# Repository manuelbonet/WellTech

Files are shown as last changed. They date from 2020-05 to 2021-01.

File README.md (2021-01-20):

# WellTech

WellTech is a school project developed by Manuel Bonet, Martín Subirá and Pablo Mellado in order to use technology as a way to improve our daily lives as students and change the ways we learn. To achieve this goal, we decided to create two different devices: a [weather station](WeatherStation) and a [classroom quality sensor](ClassroomQualitySensor).

The classroom quality sensors measure parameters that we consider key to be able to study in a comfortable environment such as temperature, humidity, sound volume and the CO<sub>2</sub> concentration in air. This last value might seem weird, but there are several studies which have found a relationship between the level of carbon dioxide in the air and the cognitive ability of a person. Given that this is precisely an ability that students need to put in practice, it is a very important parameter to control.

We have also created a weather station that monitors data such as temperature, pressure, humidiity, wind speed and direction and CO<sub>2</sub> concentration. This is because we consider that a very effective way to have students learn information is through practical activities which can be connected to as many subjects as possible. We believe that such a project could be used in a variety of subjects such as Technology (creation of the structure and the circuit), Computer Science (coding), Physics and Chemistry (understanding of meteorological phenomena) and Mathematics (statistics, processing of the raw data). Another advantage to such a project is that pupils have an active role in learning which makes it more difficult to distract themselves, and being able to collect their own data provides an incentive not present in traditional theoretical exercises.

The data collected by these two devices is sent through the [TheThingsNetwork](https://www.thethingsnetwork.org/) LoRaWAN network and the information is stored using [ThingSpeak](https://thingspeak.com/). As a way to debug any possible problem there might be, they also send the data they collect through the serial port and through Bluetooth with the pairing code 2468.

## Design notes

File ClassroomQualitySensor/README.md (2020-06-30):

# Classroom quality sensor

## Parameters

The parameters that the classroom quality sensor measures are:
* Temperature (°C)
* Pressure (hPa)
* Relative humidity (%)
* Volume (dB)
* CO<sub>2</sub> concentration in air (ppm)

## Hardware

In terms of processing power, we decided to go for a TTGO LoRa32 with an OLED screen, which provides LoRaWAN, Bluetooth and WiFi (not used) communication as well as a handy screen from which to easily debug any possible problem.

To power the sensor, it is as simple as using a 5V 1A micro USB phone charger.

The sensors used for the project are:
* BME280 (with I<sup>2</sup>C output)
* Three electret microphones
  * One without any gain (i.e. the capsule itself)
  * One with adjustable gain set at minimum
  * One with adjustable gain set at maximum
* MH-Z14A
* Push button (to calibrate the CO<sub>2</sub>sensor if it were needed)

A functional diagram of the wiring can be found below.

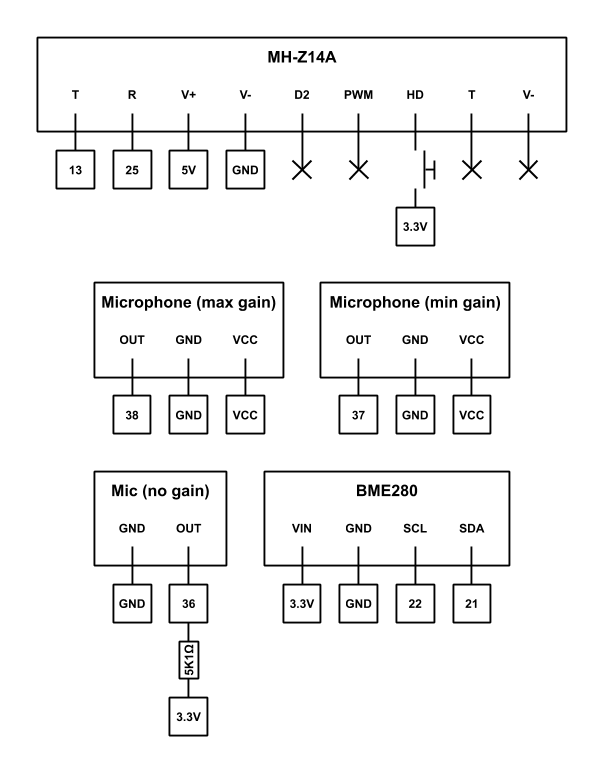
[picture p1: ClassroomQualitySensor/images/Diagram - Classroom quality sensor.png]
Wiring


## Software

The TTGO LoRa32 board can be programmed with Arduino IDE after installing the board through the board manager. The main code (classroomquality.ino) depends on the libraries that have to be added before trying to compile it. The libraries are property of their respective owners and they are under their respective licenses. I have uploaded them to the folder as a way to simplify finding and installing them.

The measured values are sent through the TTN network as comma-separated values and they have to be parsed before they arrive to the ThingSpeak integration. To decode and convert this data, the following snippets are needed under "Payload format":

```javascript
function Decoder(bytes, port) {
  while (bytes[bytes.length - 1] === 0){
    bytes.pop();
  }
  
  text = "";
  
   for (i = 0; i < bytes.length; i++){
     text += String.fromCharCode(bytes[i]);
   }
   
   return {"text": text};
}
```

```javascript
function Converter(decoded, port) {
  
   dividedText = decoded["text"].split("/");
   
   temperature = parseFloat(dividedText[0]);
   pressure = parseFloat(dividedText[1]);
   humidity = parseFloat(dividedText[2]);
   volume = parseFloat(dividedText[3]);
   CO2 = parseFloat(dividedText[4]);
   
   convertedData = {};
   
   if(!isNaN(temperature)){
     convertedData["field1"] = temperature;
   }
   
   if(!isNaN(pressure)){
     convertedData["field2"] = pressure;
   } 
   
   if(!isNaN(humidity)){
     convertedData["field3"] = humidity;
   }
   
   if(!isNaN(volume)){
     convertedData["field4"] = volume;
   }
   
   if(!isNaN(CO2)){
     convertedData["field5"] = CO2;
   }
  
  return convertedData;
}
```

These two snippets are prepared to have the ThingSpeak channels in the same order as written in the [Parameters](#parameters) section.

## Sound calibration

Due to the fact that electret microphones do not output the volume of the sound they capture in decibels, a relationship between the peak-to-peak voltage and the volume needs to be found. [Here](https://docs.google.com/spreadsheets/d/1mHTgkDXV53TCKcUPq5pmppE6GQpHShiHMCgk4wV-P8s/edit?usp=sharing) is a spreadsheet that calculates this equivalence given some empirical measurements.

## Box

The sensors have to fit in a box, which should have enough holes so that both air and sound can easily get inside. We have provided a box which directly fits a 15x9 cm perfboard and holes big enough to achieve this.

## Cost

This is a cheaper project, its cost is of around €45. The two main costs of the classroom quality sensor are the TTGO LoRa32 and the MH-Z14A, each costing around €17.

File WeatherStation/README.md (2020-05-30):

# Weather station

## Parameters

The parameters that the weather station provides are:
* Temperature (°C)
* Apparent temperature (°C)
* Pressure (hPa)
* Relative humidity (%)
* Dew point (°C)
* Wind speed (km/h)
* Wind direction (in increments of 22.5°)
* CO<sub>2</sub> concentration in air (ppm)

## Hardware

In terms of processing power, we decided to go for a TTGO LoRa32 with an OLED screen, which provides LoRaWAN, Bluetooth and WiFi (not used) communication as well as a handy screen from which to easily debug any possible problem.

Regarding powering the weather station, we went for a 12V solar panel. This is because we wanted to be able to place it in the most optimal location to take good readings without having to be close to a power outlet. Dtue to this, we also had to create a sturdy structure in order to place the solar panel on top. The reason why we chose a 12V system specifically is because the anemometer and the wind vane run at that voltage, but because the CO<sub>2</sub> sensor and the TTGo LoRa32 need to be powered with 5V we also had to include a 12V-5V buck converter. All other components run at 3.3V, but the TTGO LoRa32 board generates this voltage.

The sensors used for the project are:
* DS18B20
* BME280 (with I<sup>2</sup>C output)
* Anemometer and wind vane (we used [these](https://es.aliexpress.com/item/33019729997.html), specifically the ones that output a 0-5V signal)
* Trimmer potentiometer (to calibrate the wind direction)
* MH-Z14A
* Push button (to calibrate the CO<sub>2</sub> sensor if it were needed)

A functional diagram of the wiring can be found below.

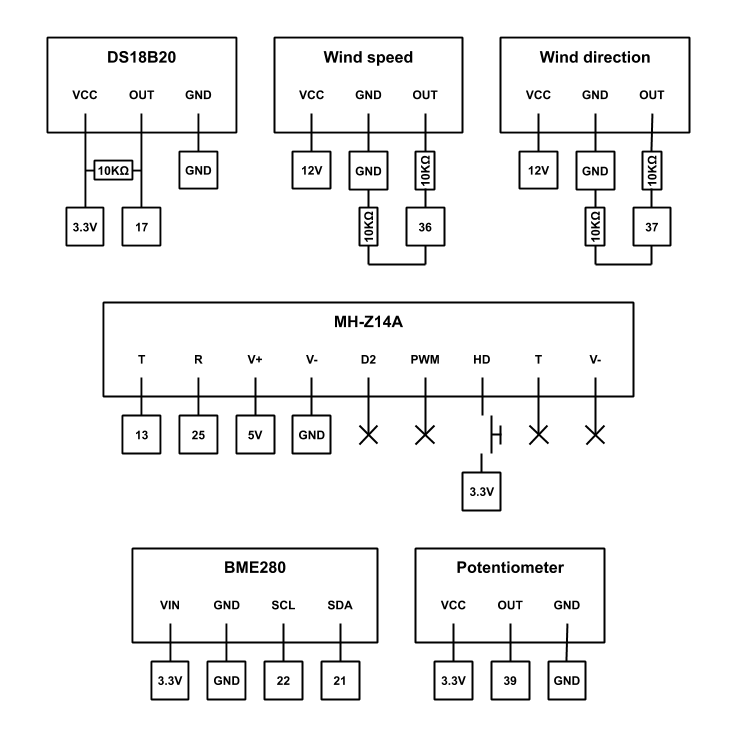
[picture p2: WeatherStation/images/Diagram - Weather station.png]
Wiring


## Software

The TTGO LoRa32 board can be programmed with Arduino IDE after installing the board through the board manager. The main code (weatherstation.ino) depends on the libraries that have to be added before trying to compile it. The libraries are property of their respective owners and they are under their respective licenses. I have uploaded them to the folder as a way to simplify finding and installing them.

The measured values are sent through the TTN network as comma-separated values and they have to be parsed before they arrive to the ThingSpeak integration. To decode and convert this data, the following snippets are needed under "Payload format":

```javascript
function Decoder(bytes, port) {
  while (bytes[bytes.length - 1] === 0){
    bytes.pop();
  }
  
  text = "";
  
   for (i = 0; i < bytes.length; i++){
     text += String.fromCharCode(bytes[i]);
   }
   
   return {"text": text};
}
```

```javascript
function Converter(decoded, port) {
  
   dividedText = decoded["text"].split("/");
   
   temperature = parseFloat(dividedText[0]);
   apparentTemperature = parseFloat(dividedText[1]);
   pressure = parseFloat(dividedText[2]);
   humidity = parseFloat(dividedText[3]);
   dewPoint = parseFloat(dividedText[4]);
   windSpeed = parseFloat(dividedText[5]);
   windDirection = parseFloat(dividedText[6]);
   CO2 = parseFloat(dividedText[7]);
   
   convertedData = {};
   
   if(!isNaN(temperature)){
     convertedData["field1"] = temperature;
   }
   
   if(!isNaN(apparentTemperature)){
     convertedData["field2"] = apparentTemperature;
   }
   
   if(!isNaN(pressure)){
     convertedData["field3"] = pressure;
   }

   if(!isNaN(humidity)){
     convertedData["field4"] = humidity;
   }

   if(!isNaN(dewPoint)){
     convertedData["field5"] = dewPoint;
   }
   
   if(!isNaN(windSpeed)){
     convertedData["field6"] = windSpeed;
   }
   
   if(!isNaN(windDirection)){
     convertedData["field7"] = windDirection;
   }

   if(!isNaN(CO2)){
     convertedData["field8"] = CO2;
   }
  
  return convertedData;
}
```

These two snippets are prepared to have the ThingSpeak channels in the same order as written in the [Parameters](#parameters) section.

## Best practices for measurements

There are several things that should be considered when deciding the structure and the location for the weather station collected in the World Meteorological Organizations' [Guide to Meteorological Instruments and Methods of Observation](https://library.wmo.int/index.php?lvl=notice_display&id=12407). However, some of these requirements turn out to be very difficult to satisfy with a setup like ours, especially those related to wind. Nevertheless, the data collected with such a weather station, although not perfect, is more than good enough to be able to learn from.

Given that these criteria are almost impossible to follow in the context of a school, it is very important to place the anemometer and vane as high and as far away as possible from any obstacle even if they are not met. Therefore, we suggest placing the weather station as far away from any tall buildings as possible and having the anemometer and wind vane at a height of at least 2 m.

## Solar power

If the weather station is solar powered, other factors should also be considered, the main one being that the weather station should be placed in such a place where ideally no shadow can be cast over the solar panel.

In terms of which solar panel and battery to choose, it is important to calculate their sizes. There are websites online and mobile apps that make this process easier. The power consumption of the weather station (with a 30% safety margin) is of 1.8W or 43.2Wh/day. Regarding the position of the solar panel, it should be pointing towards the South in the Northern Hemisphere and the North in the Southern Hemisphere, and its tilt should be appropriate to the season of year and the geographical latitude.

## Cost

This is not a cheap project, it cost us around €300 in components to build it. However, there are things that can be removed to lower the price to a much more affordable price point.

Powering the weather station through solar power is one of the main extra costs. Around €100 of that price comes directly from the solar panel, the charge controller and the battery we used. Removing the solar panel would also mean that the cost of the structure (€100) could decrease as it would not have to hold these components.

The other main source of price comes from the anemometer and the wind vane, which cost around €65. If the wind vane were not to be used, the trimmer potentiometer would no longer be necessary. However, in order to do this properly, the main code and the TTN snippets would have to be changed.

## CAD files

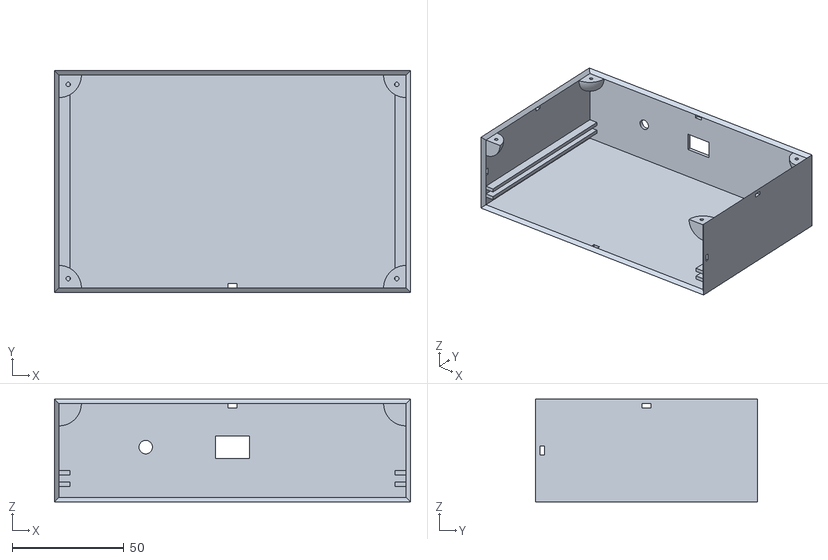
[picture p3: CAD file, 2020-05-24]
ClassroomQualitySensor/box/Box - Classroom quality sensor.stl
159.0 x 99.0 x 46.0

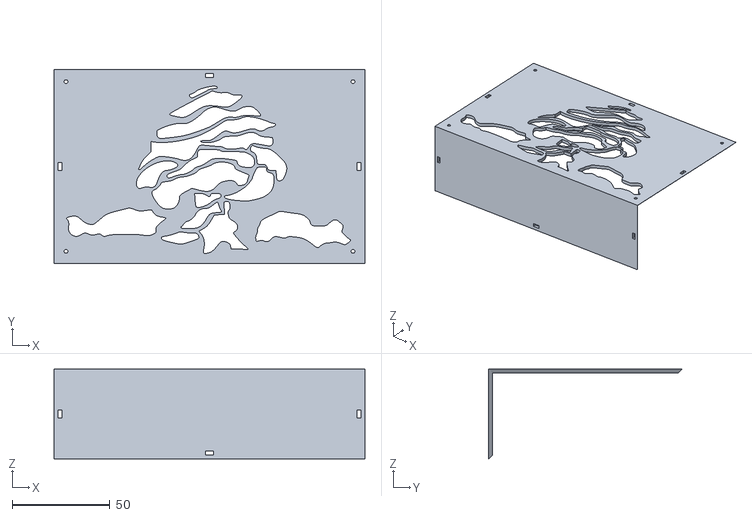
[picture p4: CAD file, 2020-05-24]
ClassroomQualitySensor/box/Lid - Classroom quality sensor.stl
159.0 x 99.0 x 46.0

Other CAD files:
ClassroomQualitySensor/box/Classroom quality sensor.f3d
ClassroomQualitySensor/box/Classroom quality sensor.skp

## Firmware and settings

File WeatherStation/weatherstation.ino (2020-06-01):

//VERSION
//Date: 2020-05-31

//PINS
//Screen: 4 (SDA), 15 (SCL), 16 (RST)
//General I2C (BME280): 21 (SDA), 22 (SCL)
//OneWire: 17
//Wind speed: 36
//Wind direction: 37
//Correction angle potentiometer: 39
//Serial (CO2): 13 (RX), 25 (TX)

//BEFORE LOADING THE CODE
//Remember to change NWKSKEY, APPSKEY and DEVADDR to whichever values are set on your TheThingsNetwork application and device
//If you are in range of a multiple channel gateway, change MULTICHANNEL to 1
//Before using the values of decibels, remember to calibrate the microphones

#include <math.h>
#include <lmic.h>
#include <hal/hal.h>
#include <SPI.h>
#include <Wire.h>
#include <Adafruit_SSD1306.h>
#include <Adafruit_BME280.h>
#include <DallasTemperature.h>
#include <BluetoothSerial.h>

static const PROGMEM u1_t NWKSKEY[16] = { 0x00, 0x00, 0x00, 0x00, 0x00, 0x00, 0x00, 0x00, 0x00, 0x00, 0x00, 0x00, 0x00, 0x00, 0x00, 0x00 };
static const PROGMEM u1_t APPSKEY[16] = { 0x00, 0x00, 0x00, 0x00, 0x00, 0x00, 0x00, 0x00, 0x00, 0x00, 0x00, 0x00, 0x00, 0x00, 0x00, 0x00 };

static const u4_t DEVADDR = 0x00000000 ;

#define MULTICHANNEL 0

void os_getArtEui (u1_t* buf) { }
void os_getDevEui (u1_t* buf) { }
void os_getDevKey (u1_t* buf) { }

#define WIND_INTERVAL 1
#define TX_INTERVAL 60

unsigned long lastWind = - WIND_INTERVAL * 1000;
unsigned long lastTX = - TX_INTERVAL * 1000;
unsigned long millisOverflows = -1;
bool sendValues = false;

const byte disableABC[] = {0xFF, 0x01, 0x79, 0xA0, 0x00, 0x00, 0x00, 0x00, 0xE6};
const byte readCO2[] = {0xFF, 0x01, 0x86, 0x00, 0x00, 0x00, 0x00, 0x00, 0x79};

float insideTemperature;
float temperature;
float apparentTemperature;
float dewPoint;
float pressure;
float insideHumidity;
float humidity;
float windSpeed;
float maxWindSpeed;
float windDirection;
float adjustedWindDirection;
float cumulativeWindX;
float cumulativeWindY;
float averageWindDirection;
float correctionAngle;
float CO2;

String text;
static uint8_t textBytes[256];

const lmic_pinmap lmic_pins = {
  .nss = 18,
  .rxtx = LMIC_UNUSED_PIN,
  .rst = 14,
  .dio = {26, 33, 32},
};

Adafruit_SSD1306 display(128, 64, &Wire, 16);
Adafruit_BME280 bme280;
OneWire oneWire(17);
DallasTemperature ds18b20(&oneWire);
BluetoothSerial bluetooth;

void onEvent (ev_t ev) {
  Serial.print(os_getTime());
  Serial.print(": ");
  switch (ev) {
    case EV_SCAN_TIMEOUT:
      Serial.println(F("EV_SCAN_TIMEOUT"));
      break;
    case EV_BEACON_FOUND:
      Serial.println(F("EV_BEACON_FOUND"));
      break;
    case EV_BEACON_MISSED:
      Serial.println(F("EV_BEACON_MISSED"));
      break;
    case EV_BEACON_TRACKED:
      Serial.println(F("EV_BEACON_TRACKED"));
      break;
    case EV_JOINING:
      Serial.println(F("EV_JOINING"));
      break;
    case EV_JOINED:
      Serial.println(F("EV_JOINED"));
      break;
    case EV_RFU1:
      Serial.println(F("EV_RFU1"));
      break;
    case EV_JOIN_FAILED:
      Serial.println(F("EV_JOIN_FAILED"));
      break;
    case EV_REJOIN_FAILED:
      Serial.println(F("EV_REJOIN_FAILED"));
      break;
    case EV_TXCOMPLETE:
      Serial.println(F("EV_TXCOMPLETE (includes waiting for RX windows)"));
      if (LMIC.txrxFlags & TXRX_ACK)
        Serial.println(F("Received ack"));
      if (LMIC.dataLen) {
        Serial.println(F("Received "));
        Serial.println(LMIC.dataLen);
        Serial.println(F(" bytes of payload"));
      }
      break;
    case EV_LOST_TSYNC:
      Serial.println(F("EV_LOST_TSYNC"));
      break;
    case EV_RESET:
      Serial.println(F("EV_RESET"));
      break;
    case EV_RXCOMPLETE:
      Serial.println(F("EV_RXCOMPLETE"));
      break;
    case EV_LINK_DEAD:
      Serial.println(F("EV_LINK_DEAD"));
      break;
    case EV_LINK_ALIVE:
      Serial.println(F("EV_LINK_ALIVE"));
      break;
    default:
      Serial.println(F("Unknown event"));
      break;
  }

  Serial.println();
}

float analogReadVolts(unsigned int pin, unsigned int readings = 100) {
  float values[] = {0,    1,   77,  197,  318,  438,  564,  694,  811,  931, 1069, 1180, 1306, 1435, 1562, 1680, 1806, 1924, 2053, 2174, 2294, 2418, 2535, 2674, 2801, 2927, 3071, 3221, 3389, 3587, 3798, 4031, 4095, 4095};
  float volts[] =  {0,  0.1,  0.2,  0.3,  0.4,  0.5,  0.6,  0.7,  0.8,  0.9,  1.0,  1.1,  1.2,  1.3,  1.4,  1.5,  1.6,  1.7,  1.8,  1.9,  2.0,  2.1,  2.2,  2.3,  2.4,  2.5,  2.6,  2.7,  2.8,  2.9,  3.0,  3.1,  3.2,  3.3};

  long x = 0;

  for (int i = 0; i < readings; i++) {
    x += analogRead(pin);
    delayMicroseconds(500);
  }

  x /= readings;

  for (int i = 0; i < sizeof(values) / sizeof(values[0]); i++) {
    if (x <= values[i]) {

      if (i == 0) {
        return volts[0];
      }

      if (values[i - 1] == values[i]) {
        return (volts[i - 1] + volts[i]) / 2;
      }

      return (x - values[i - 1]) / (values[i] - values[i - 1]) * (volts[i] - volts[i - 1]) + volts[i - 1];
    }
  }
  return volts[sizeof(volts) / sizeof(volts[0]) - 1];
}

void setup() {
  Wire.begin(4, 15);
  Serial.begin(115200);
  Serial.println("Starting...");

  bluetooth.begin("Weather station");
  bluetooth.setPin("2468");

  Serial1.begin(9600, SERIAL_8N1, 13, 25);
  Serial1.write(disableABC, 9);

  display.begin(SSD1306_SWITCHCAPVCC, 0x3C);
  display.clearDisplay();
  display.setTextColor(SSD1306_WHITE);
  display.setCursor(0, 0);
  display.println("Starting...");
  display.display();

  Wire.begin(21, 22);
  bme280.begin();
  ds18b20.begin();

#ifdef VCC_ENABLE
  pinMode(VCC_ENABLE, OUTPUT);
  digitalWrite(VCC_ENABLE, HIGH);
  delay(1000);
#endif

  os_init();
  LMIC_reset();

#ifdef PROGMEM
  uint8_t appskey[sizeof(APPSKEY)];
  uint8_t nwkskey[sizeof(NWKSKEY)];
  memcpy_P(appskey, APPSKEY, sizeof(APPSKEY));
  memcpy_P(nwkskey, NWKSKEY, sizeof(NWKSKEY));
  LMIC_setSession (0x1, DEVADDR, nwkskey, appskey);
#else
  LMIC_setSession (0x1, DEVADDR, NWKSKEY, APPSKEY);
#endif

#if defined(CFG_eu868)
#if (MULTICHANNEL)
  LMIC_setupChannel(0, 868100000, DR_RANGE_MAP(DR_SF12, DR_SF7),  BAND_CENTI);
  LMIC_setupChannel(1, 868300000, DR_RANGE_MAP(DR_SF12, DR_SF7B), BAND_CENTI);
  LMIC_setupChannel(2, 868500000, DR_RANGE_MAP(DR_SF12, DR_SF7),  BAND_CENTI);
  LMIC_setupChannel(3, 867100000, DR_RANGE_MAP(DR_SF12, DR_SF7),  BAND_CENTI);
  LMIC_setupChannel(4, 867300000, DR_RANGE_MAP(DR_SF12, DR_SF7),  BAND_CENTI);
  LMIC_setupChannel(5, 867500000, DR_RANGE_MAP(DR_SF12, DR_SF7),  BAND_CENTI);
  LMIC_setupChannel(6, 867700000, DR_RANGE_MAP(DR_SF12, DR_SF7),  BAND_CENTI);
  LMIC_setupChannel(7, 867900000, DR_RANGE_MAP(DR_SF12, DR_SF7),  BAND_CENTI);
  LMIC_setupChannel(8, 868800000, DR_RANGE_MAP(DR_FSK,  DR_FSK),  BAND_MILLI);
#else
  LMIC_setupChannel(0, 868100000, DR_RANGE_MAP(DR_SF12, DR_SF7),  BAND_CENTI);
  LMIC_setupChannel(1, 868100000, DR_RANGE_MAP(DR_SF12, DR_SF7),  BAND_CENTI);
  LMIC_setupChannel(2, 868100000, DR_RANGE_MAP(DR_SF12, DR_SF7),  BAND_CENTI);
  LMIC_setupChannel(3, 868100000, DR_RANGE_MAP(DR_SF12, DR_SF7),  BAND_CENTI);
  LMIC_setupChannel(4, 868100000, DR_RANGE_MAP(DR_SF12, DR_SF7),  BAND_CENTI);
  LMIC_setupChannel(5, 868100000, DR_RANGE_MAP(DR_SF12, DR_SF7),  BAND_CENTI);
  LMIC_setupChannel(6, 868100000, DR_RANGE_MAP(DR_SF12, DR_SF7),  BAND_CENTI);
  LMIC_setupChannel(7, 868100000, DR_RANGE_MAP(DR_SF12, DR_SF7),  BAND_CENTI);
  LMIC_setupChannel(8, 868100000, DR_RANGE_MAP(DR_SF12, DR_SF7),  BAND_CENTI);
#endif
#elif defined(CFG_us915)
  LMIC_selectSubBand(1);
#endif

  LMIC_setLinkCheckMode(0);
  LMIC.dn2Dr = DR_SF9;
  LMIC_setDrTxpow(DR_SF7, 14);
}

void loop() {
  unsigned long millisNow = millis();

  if ((millisNow >= (unsigned long)(lastWind + 1000 * WIND_INTERVAL)) && (((unsigned long)(lastWind + 1000 * WIND_INTERVAL) > lastWind) || ((unsigned long)(millisNow + 1000 * WIND_INTERVAL) > millisNow))) {
    lastWind = millisNow;

    windSpeed = 43.2 * analogReadVolts(36);
    if (windSpeed > maxWindSpeed) {
      maxWindSpeed = windSpeed;
    }
    windDirection = round(6.95652173913 * analogReadVolts(37)) * 22.5;
    correctionAngle = floor(analogReadVolts(39) * 5) * 22.5; if (correctionAngle == 360) correctionAngle = 337.5;
    adjustedWindDirection = windDirection - correctionAngle; while (adjustedWindDirection >= 360) adjustedWindDirection -= 360;  while (adjustedWindDirection < 0) adjustedWindDirection += 360;
    cumulativeWindX += cos(adjustedWindDirection * PI / 180.0);
    cumulativeWindY += sin(adjustedWindDirection * PI / 180.0);

    Wire.begin(4, 15);

    display.fillRect(0, 32, 128, 16, 0);
    display.setCursor(0, 32);
    display.println(String(windSpeed, 2) + "km/h " + String(adjustedWindDirection) + "*");
    display.println("WCA: " + String(correctionAngle, 1) + "*");
    display.display();
  }

  if ((millisNow >= (unsigned long)(lastTX + 1000 * TX_INTERVAL)) && (((unsigned long)(lastTX + 1000 * TX_INTERVAL) > lastTX) || ((unsigned long)(millisNow + 1000 * TX_INTERVAL) > millisNow))) {
    if (millisNow < lastTX){
      millisOverflows++;
    }

    lastTX = millis();

    Wire.begin(21, 22);

    ds18b20.requestTemperatures();
    insideTemperature = bme280.readTemperature();
    temperature = ds18b20.getTempCByIndex(0);
    delay(50);
    pressure = bme280.readPressure() / 100;
    delay(50);
    insideHumidity = bme280.readHumidity();
    humidity = constrain(insideHumidity * exp((18.768 - insideTemperature / 234.5) * (insideTemperature / (257.1 + insideTemperature)) - (18.768 - temperature / 234.5) * (temperature / (257.1 + temperature))), 0, 100);
    dewPoint = 1.0 / 2.0 * (4379.991 - 234.5 * (log(humidity / 100) + (18.678 - temperature / 234.5) * (temperature / (257.14 + temperature))) - sqrt(pow(234.5 * (log(humidity / 100) + (18.678 - temperature / 234.5) * (temperature / (257.14 + temperature))) - 4379.991, 2) - 241197.32 * (log(humidity / 100) + (18.678 - temperature / 234.5) * (temperature / (257.14 + temperature)))));
    averageWindDirection = round(atan2(cumulativeWindY, cumulativeWindX) / PI * 180.0 / 22.5) * 22.5; while (averageWindDirection < 0) averageWindDirection += 360;
    if (temperature >= 26 && humidity >= 40) {
      apparentTemperature = -8.78469476 + 1.61139411 * temperature + 2.338548839 * humidity - 0.14611605 * temperature * humidity - 0.012308094 * pow(temperature, 2) - 0.016424828 * pow(humidity, 2) + 0.002211732 * pow(temperature, 2) * humidity + 0.00072546 * temperature * pow(humidity, 2) - 0.000003582 * pow(temperature, 2) * pow(humidity, 2);
    } else if (temperature <= 10 && maxWindSpeed >= 3.2) {
      apparentTemperature =  13.1267 + 0.6215 * temperature - 11.37 * pow(maxWindSpeed * 1.5, 0.16) + 0.3965 * temperature * pow(maxWindSpeed * 1.5, 0.16);
    } else {
      apparentTemperature = temperature;
    }

    byte bufferCO2[9];
    while (Serial1.available()) {
      Serial1.read();
    }
    Serial1.write(readCO2, 9);
    Serial1.readBytes(bufferCO2, 9);
    CO2 = (unsigned int)(bufferCO2[2] && B00011111) * 256 + (unsigned int)bufferCO2[3];

    uint64_t fullMillis = lastTX + 4294967296 * millisOverflows;
    unsigned long fullMillisA = fullMillis / 1E16;
    unsigned long fullMillisB = (fullMillis - fullMillisA * 1E16) / 1E8;
    unsigned long fullMillisC = fullMillis - fullMillisA - fullMillisB;

    uint64_t tempTX = fullMillis;
    int dayTX = 0;
    int hourTX = 0;
    int minuteTX = 0;

    while (tempTX >= 86400E3) {
      tempTX -= 86400E3;
      dayTX++;
    }
    while (tempTX >= 3600E3) {
      tempTX -= 3600E3;
      hourTX++;
    }
    while (tempTX >= 60E3) {
      tempTX -= 60E3;
      minuteTX++;
    }

    Serial.print("Time: day ");
    Serial.print(dayTX);
    Serial.print(" ");
    if (hourTX < 10) {
      Serial.print("0");
    }
    Serial.print(hourTX);
    Serial.print(":");
    if (minuteTX < 10) {
      Serial.print("0");
    }
    Serial.print(minuteTX);
    Serial.print(" (");
    if (fullMillisA!=0){
      Serial.print(fullMillisA);
    }
    if (fullMillisB!=0){
      Serial.print(fullMillisB);
    } else if (fullMillisA!=0){
      Serial.print("00000000");
    }
    Serial.print(fullMillisC);
    Serial.println(" ms)");

    Serial.print("Inside temperature: ");
    Serial.print(insideTemperature, 2);
    Serial.println(" °C");

    Serial.print("Outside temperature: ");
    Serial.print(temperature, 2);
    Serial.println(" °C");

    Serial.print("Dew point: ");
    Serial.print(dewPoint, 2);
    Serial.println(" °C");

    Serial.print("Atmospheric pressure: ");
    Serial.print(pressure, 2);
    Serial.println(" hPa");

    Serial.print("Inside humidity: ");
    Serial.print(insideHumidity, 2);
    Serial.println(" %");

    Serial.print("Outside humidity: ");
    Serial.print(humidity, 2);
    Serial.println(" %");

    Serial.print("Maximum wind speed: ");
    Serial.print(maxWindSpeed, 2);
    Serial.println(" km/h");

    Serial.print("Average wind direction: ");
    Serial.print(averageWindDirection, 1);
    Serial.println("°");

    Serial.print("Apparent temperature: ");
    Serial.print(apparentTemperature, 2);
    Serial.println(" °C");

    Serial.print("CO2: ");
    Serial.print(CO2, 0);
    Serial.println(" ppm");

    bluetooth.print("Time: day ");
    bluetooth.print(dayTX);
    bluetooth.print(" ");
    if (hourTX < 10) {
      bluetooth.print("0");
    }
    bluetooth.print(hourTX);
    bluetooth.print(":");
    if (minuteTX < 10) {
      bluetooth.print("0");
    }
    bluetooth.print(minuteTX);
    bluetooth.print(" (");
    if (fullMillisA!=0){
      bluetooth.print(fullMillisA);
    }
    if (fullMillisB!=0){
      bluetooth.print(fullMillisB);
    } else if (fullMillisA!=0){
      bluetooth.print("00000000");
    }
    bluetooth.print(fullMillisC);
    bluetooth.println(" ms)");

    bluetooth.print("Inside temperature: ");
    bluetooth.print(insideTemperature, 2);
    bluetooth.println(" *C");

    bluetooth.print("Outside temperature: ");
    bluetooth.print(temperature, 2);
    bluetooth.println(" *C");

    bluetooth.print("Dew point: ");
    bluetooth.print(dewPoint, 2);
    bluetooth.println(" *C");

    bluetooth.print("Atmospheric pressure: ");
    bluetooth.print(pressure, 2);
    bluetooth.println(" hPa");

    bluetooth.print("Inside humidity: ");
    bluetooth.print(insideHumidity, 2);
    bluetooth.println(" %");

    bluetooth.print("Outside humidity: ");
    bluetooth.print(humidity, 2);
    bluetooth.println(" %");

    bluetooth.print("Maximum wind speed: ");
    bluetooth.print(maxWindSpeed, 2);
    bluetooth.println(" km/h");

    bluetooth.print("Average wind direction: ");
    bluetooth.print(averageWindDirection, 1);
    bluetooth.println("*");

    bluetooth.print("Apparent temperature: ");
    bluetooth.print(apparentTemperature, 2);
    bluetooth.println(" *C");

    bluetooth.print("CO2: ");
    bluetooth.print(CO2, 0);
    bluetooth.println(" ppm");
    bluetooth.println();

    text = "";
    text += (-80 <= temperature && temperature <= 80) ? String(temperature, 2) : "";
    text += "/";
    text += (-80 <= apparentTemperature && apparentTemperature <= 80) ? String(apparentTemperature, 2) : "";
    text += "/";
    text += (0 <= pressure && pressure <= 2000) ? String(pressure, 2) : "";
    text += "/";
    text += (0 <= humidity && humidity <= 100) ? String(humidity, 2) : "";
    text += "/";
    text += (-80 <= dewPoint && dewPoint <= 80) ? String(dewPoint, 2) : "";
    text += "/";
    text += String(maxWindSpeed, 2);
    text += "/";
    text += String(averageWindDirection, 1);
    text += "/";
    text += (0 < CO2 && CO2 <= 5000 && CO2 != 256) ? String(CO2, 0) : "";

    if (sendValues){
      Serial.print("Sending: ");
      Serial.println(text);

      for (unsigned int i = 0; i < min(text.length(), sizeof(textBytes) / sizeof(textBytes[0])); i++) {
        textBytes[i] = text.charAt(i);
      }

      if (LMIC.opmode & OP_TXRXPEND) {
        Serial.println(F("OP_TXRXPEND, not sending"));
      } else {
        LMIC_setTxData2(1, textBytes, text.length(), 0);
        Serial.println(F("Packet queued"));
      }
    } else {
      Serial.print("Not sending: ");
      Serial.println(text);
    }

    Serial.println();

    Wire.begin(4, 15);

    display.fillRect(0, 0, 128, 32, 0);
    display.setCursor(0, 0);
    display.println("Day " + String(dayTX) + " " + ((hourTX < 10) ? "0" : "") + String(hourTX) + ":" + ((minuteTX < 10) ? "0" : "") + String(minuteTX));
    display.println(String(temperature, 2) + "*C (" + String(apparentTemperature) + "*Cap)");
    display.println(String(humidity, 2) + "% " + String(dewPoint, 2) + "*Cdew");
    display.println(String(pressure, 2) + "hPa " + String(CO2, 0) + "ppm");
    display.display();

    Wire.begin(21, 22);

    maxWindSpeed = 0;
    cumulativeWindX = 0;
    cumulativeWindY = 0;

    sendValues = true;
  }

  os_runloop_once();
}
